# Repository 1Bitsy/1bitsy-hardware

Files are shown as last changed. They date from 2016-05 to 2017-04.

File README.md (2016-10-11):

# 1BitSy



This project includes 1BitSy evaluation boards. These boards are breadboard friendly STM32 (eventually other MCUs will be considered) with exposed Cortex JTAG and SWD interfaces. This allows the use of the Black Magic Probe, instead of the usually very limited built in debugger hardware.

Currently we have the following eval boards:

* 1BitSy V1.0d -> STM32F4x5RGT6

You can find the datasheet of the STM32F415RGT6 chip on the
[STMicroelectronics website](http://www.st.com/content/st_com/en/products/microcontrollers/stm32-32-bit-arm-cortex-mcus/stm32f4-series/stm32f405-415/stm32f415rg.html).

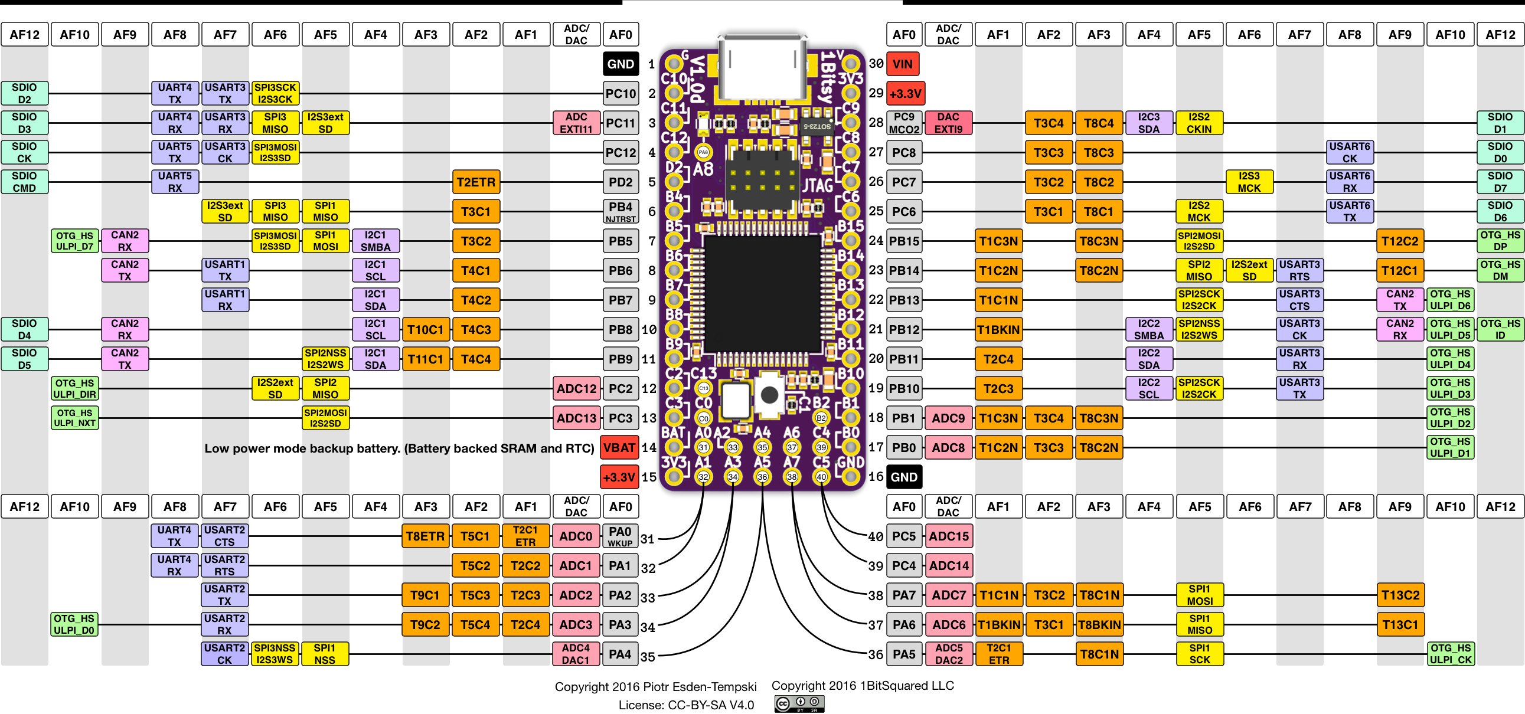
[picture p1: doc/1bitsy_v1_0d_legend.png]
1BitSy V1.0d legend

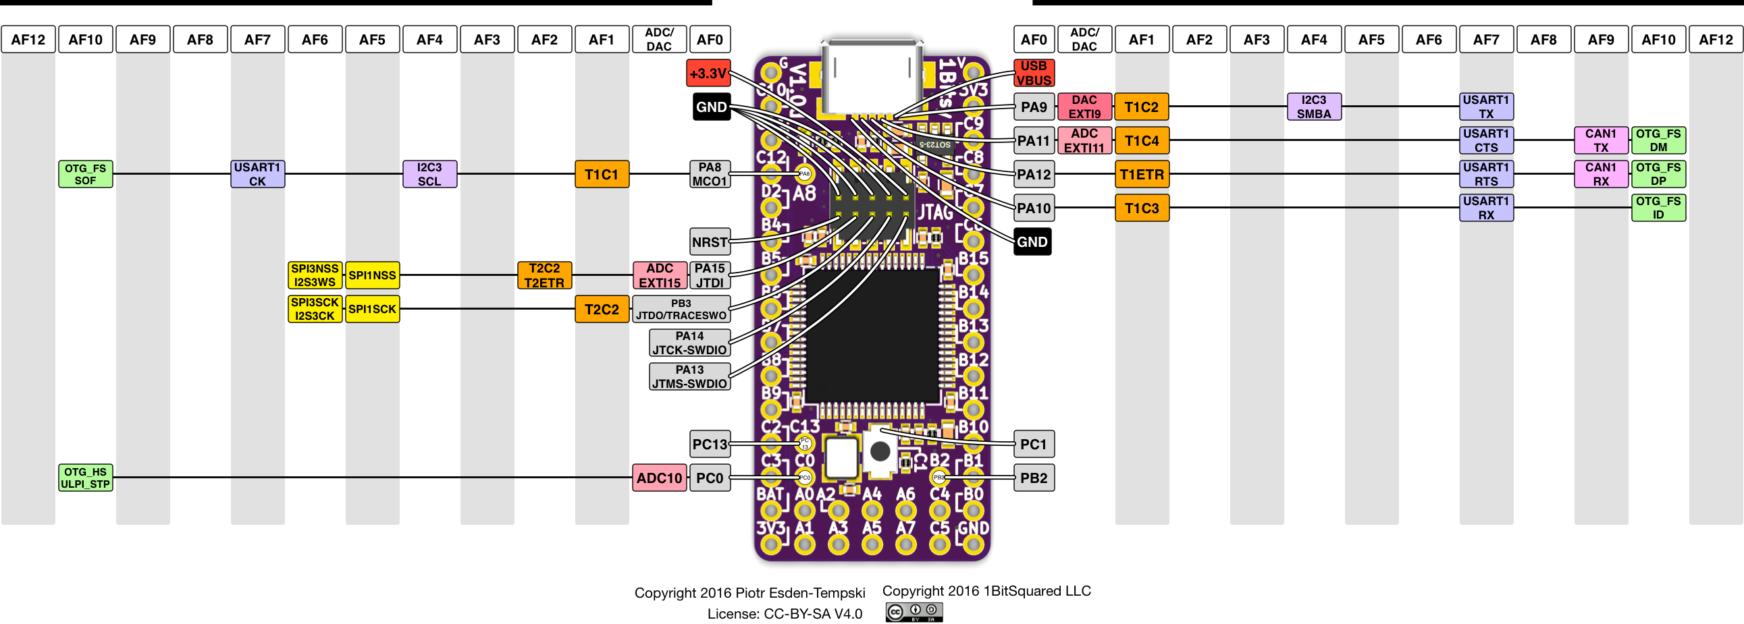
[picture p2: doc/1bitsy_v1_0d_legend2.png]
1BitSy V1.0d legend2

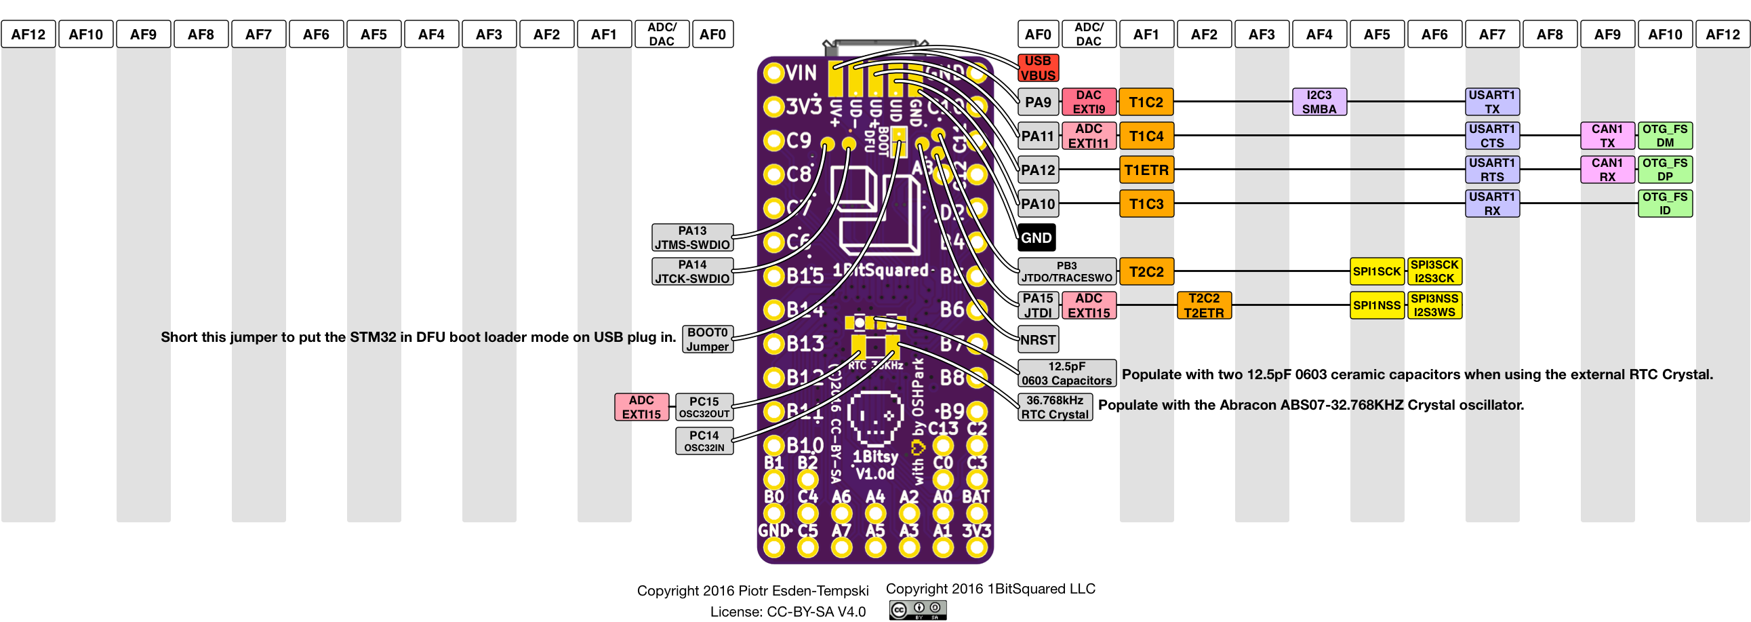
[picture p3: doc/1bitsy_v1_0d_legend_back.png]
1BitSy V1.0d legend back


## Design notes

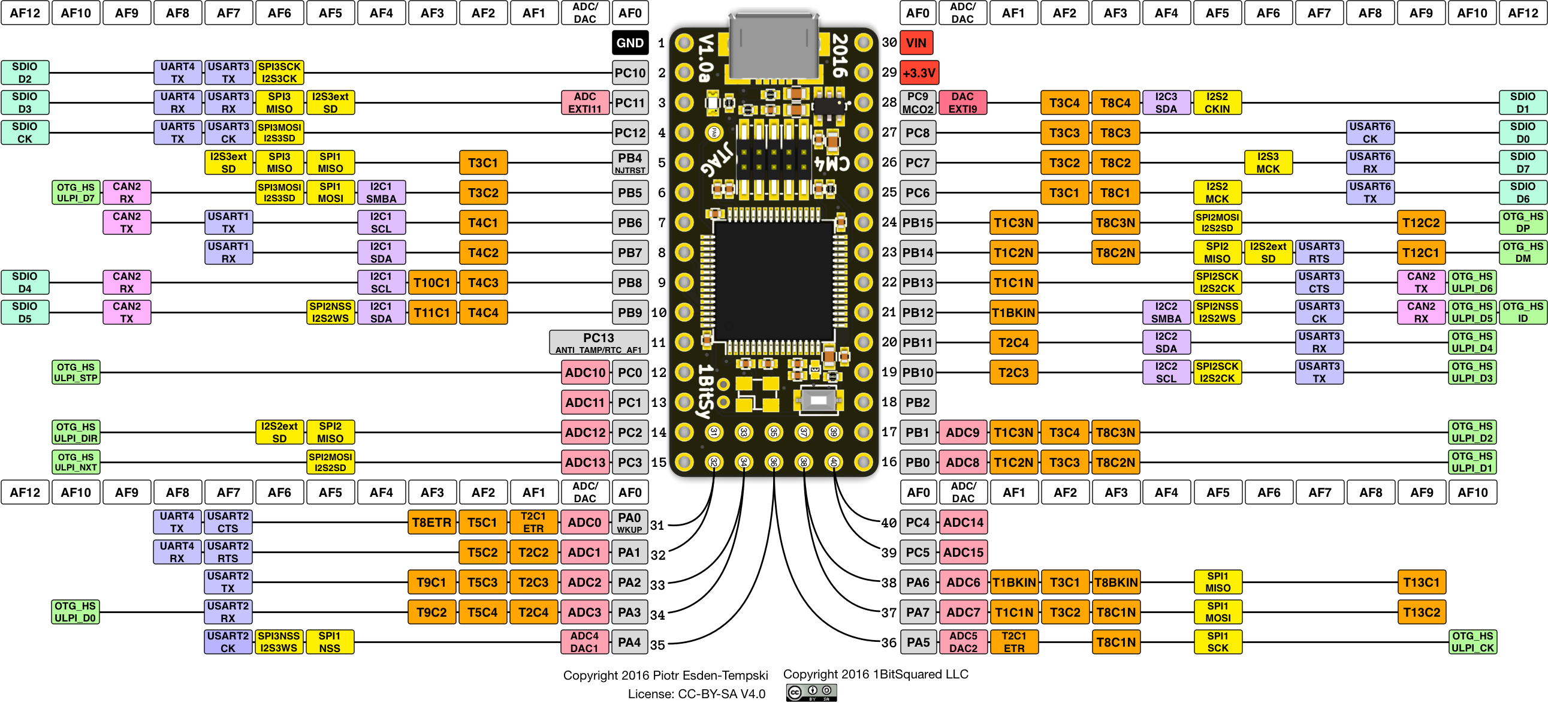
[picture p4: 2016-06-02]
doc/1bitsy_v1_0_legend.png

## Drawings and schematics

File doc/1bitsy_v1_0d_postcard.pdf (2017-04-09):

# 1Bitsy V1.0

# Open-Source debuggable ARM development board

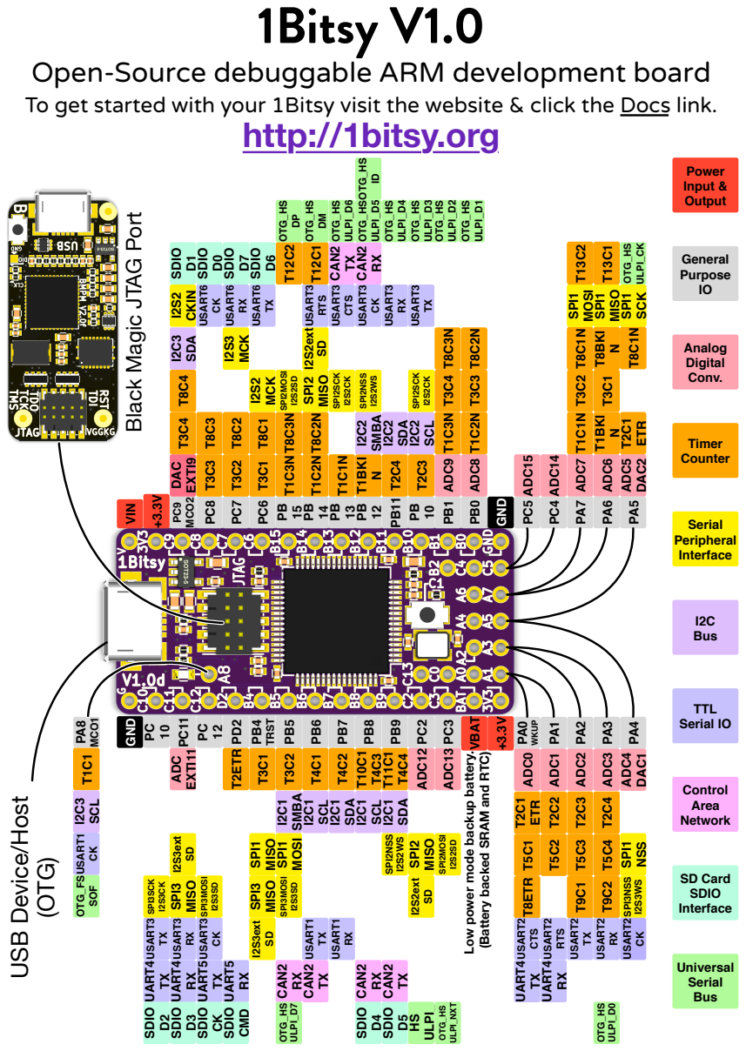
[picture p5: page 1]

To get started with your 1Bitsy visit the website & click the Docs link.

Black Magic JTAG Port

Low power mode backup battery.

(Battery backed SRAM and RTC)

# 1Bitsy V1.0

# Open-Source debuggable ARM development board

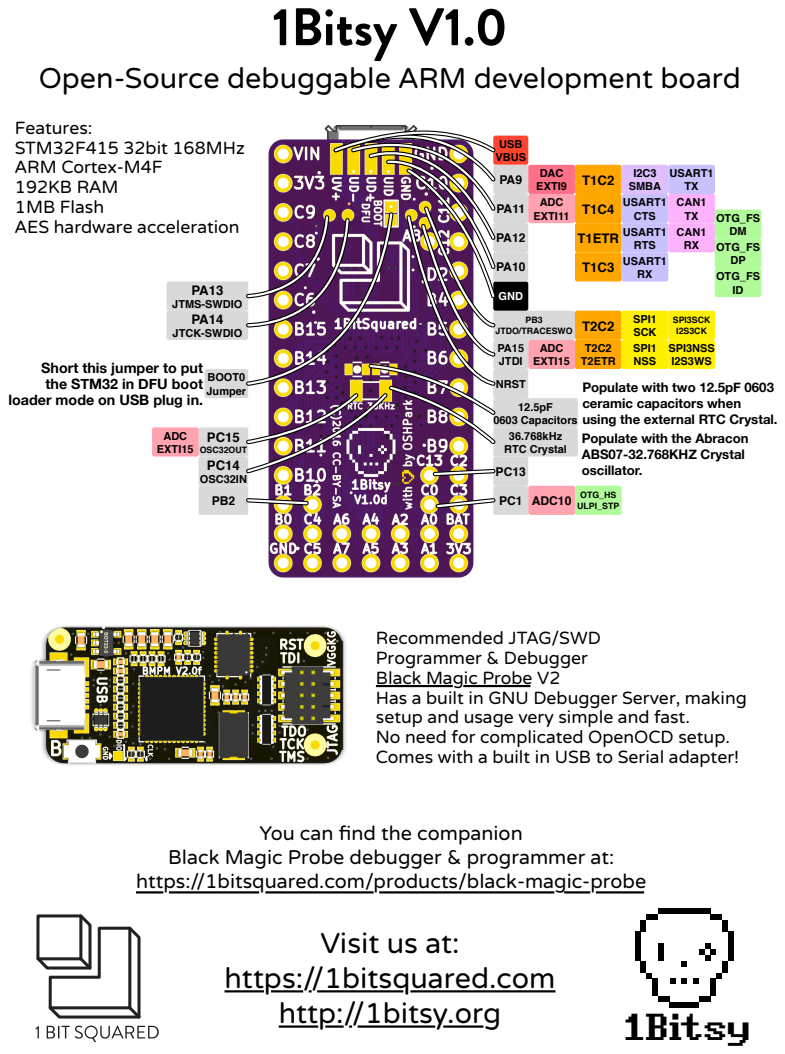
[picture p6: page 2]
USB VBUS; PA13 JTMS-SWDIO; PA14 JTCK-SWDIO; PB3 JTDO/TRACESWO PA15 JTDI; NRST; GND; T1ETR; I2C3 SMBA; USART1 TX; USART1 RX; USART1 CTS USART1 RTS; CAN1 RX; CAN1 TX; OTG_FS ID; OTG_FS DM OTG_FS DP; SPI1 NSS; SPI3NSS I2S3WS; SPI1 SCK; SPI3SCK I2S3CK; BOOT0 Jumper; 36.768kHz RTC Crystal; 12.5pF 0603 Capacitors; OSC32OUT PC14 OSC32IN; ADC EXTI15; ADC EXTI11; DAC EXTI9; ADC10 OTG_HS ULPI_STP; 1Bitsy; Features: STM32F415 32bit 168MHz ARM Cortex-M4F 192KB RAM 1MB Flash AES hardware acceleration

T2ETR
Populate with two 12.5pF 0603
ceramic capacitors when
using the external RTC Crystal.
Populate with the Abracon
ABS07-32.768KHZ Crystal
oscillator.

Short this jumper to put
the STM32 in DFU boot
loader mode on USB plug in.

Recommended JTAG/SWD
Programmer & Debugger
Black Magic Probe V2
Has a built in GNU Debugger Server, making
setup and usage very simple and fast.
No need for complicated OpenOCD setup.
Comes with a built in USB to Serial adapter!

You can find the companion

Black Magic Probe debugger & programmer at:
https://1bitsquared.com/products/black-magic-probe

Visit us at:
https://1bitsquared.com
http://1bitsy.org

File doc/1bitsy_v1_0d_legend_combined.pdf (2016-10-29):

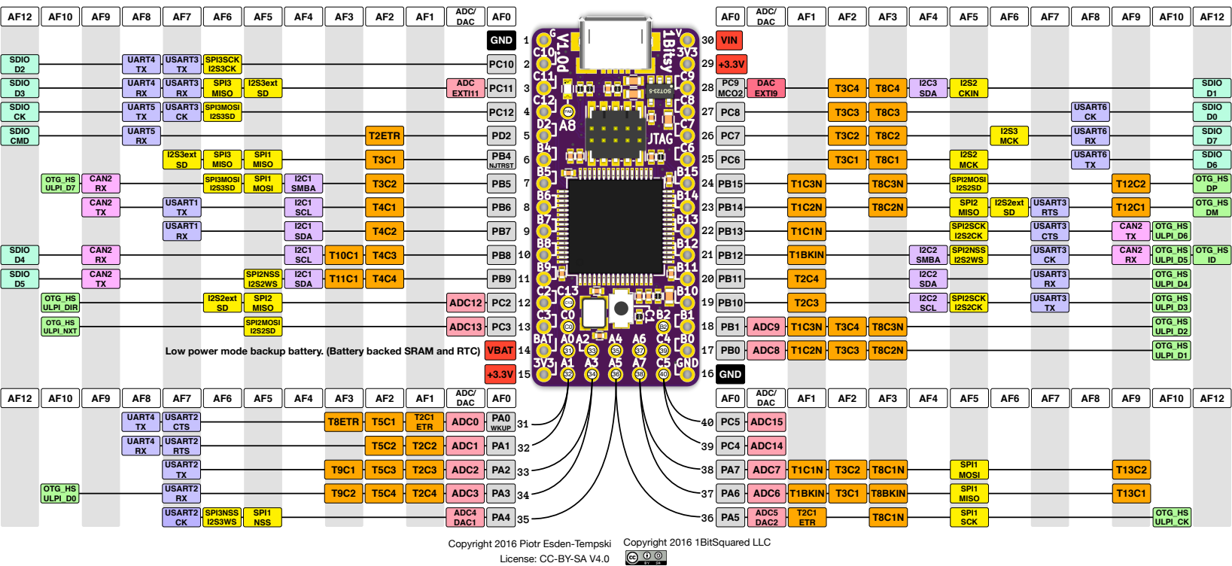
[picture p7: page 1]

Low power mode backup battery. (Battery backed SRAM and RTC) VBAT

ADC4
DAC1
Copyright 2016 Piotr Esden-Tempski Copyright 2016 1BitSquared LLC

License: CC-BY-SA V4.0

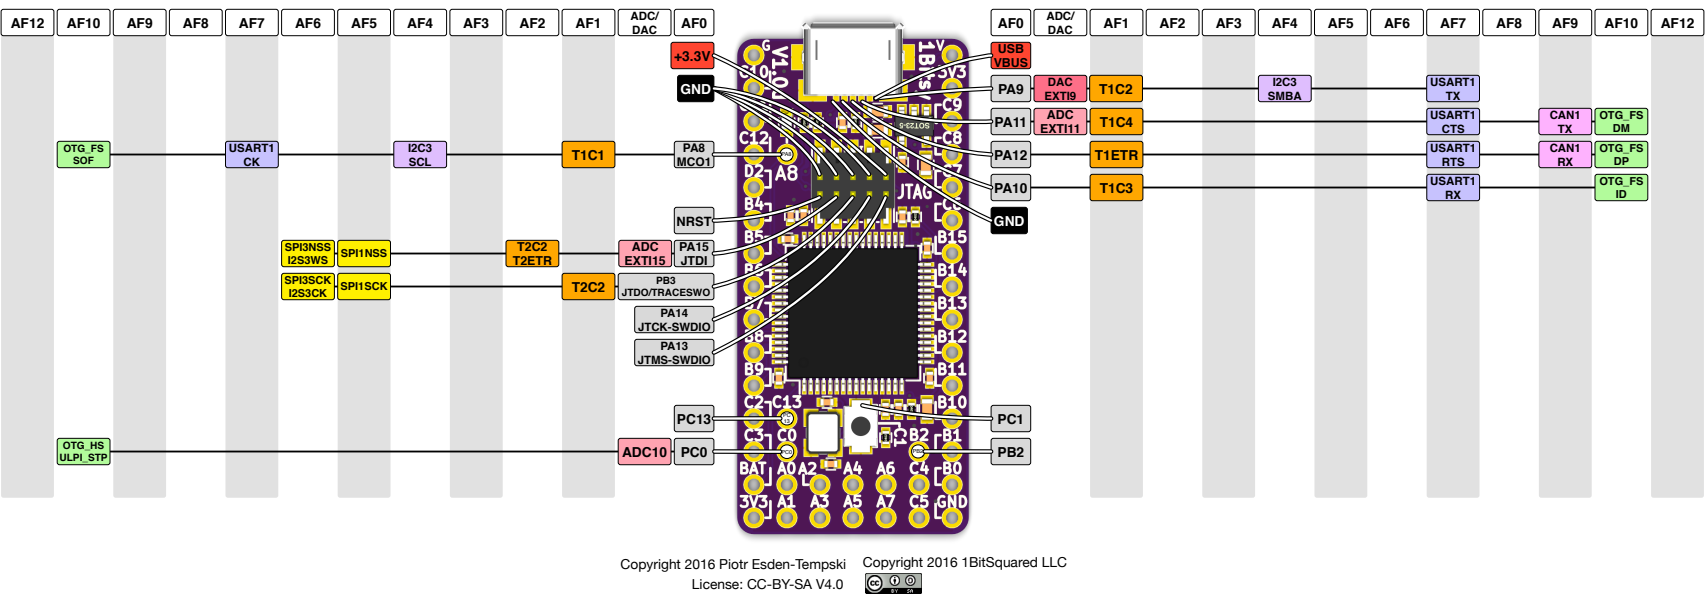
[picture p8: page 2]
ADC10 OTG_HS ULPI_STP; USB VBUS +3.3V; PA13 JTMS-SWDIO; PA14 JTCK-SWDIO; PB3 JTDO/TRACESWO; PA15 JTDI; NRST; PA8 MCO1; DAC AF12; USART1 CK; T2C2 T2ETR; T1C1 I2C3 SCL; OTG_FS SOF; GND; T1ETR; I2C3 SMBA; USART1 TX; USART1 RX; USART1 CTS; USART1 RTS; CAN1 RX; CAN1 TX; OTG_FS ID; OTG_FS DM; OTG_FS DP; SPI1NSS SPI3NSS I2S3WS; SPI1SCK SPI3SCK I2S3CK; ADC EXTI11; DAC EXTI9; ADC EXTI15

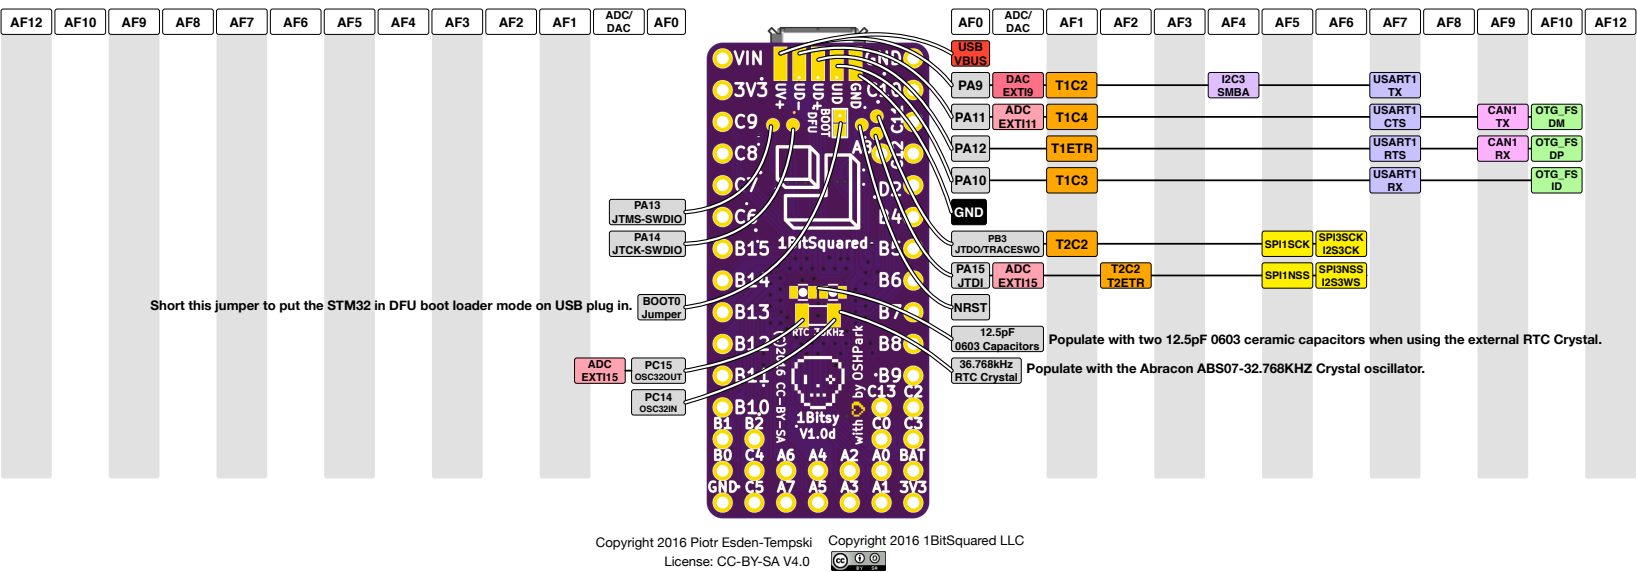
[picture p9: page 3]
USB VBUS; PA13 JTMS-SWDIO; PA14 JTCK-SWDIO; PB3 JTDO/TRACESWO; PA15 JTDI; DAC AF12; T2C2 T2ETR; GND; T1ETR; I2C3 SMBA; USART1 TX; USART1 RX; USART1 CTS; USART1 RTS; CAN1 RX; CAN1 TX; OTG_FS ID; OTG_FS DM; OTG_FS DP; SPI1NSS SPI3NSS I2S3WS; SPI1SCK SPI3SCK I2S3CK; BOOT0; 36.768kHz; PC15 OSC32OUT; PC14 OSC32IN; ADC EXTI15; ADC EXTI11; DAC EXTI9

Jumper Short this jumper to put the STM32 in DFU boot loader mode on USB plug in.

NRST
0603 Capacitors Populate with two 12.5pF 0603 ceramic capacitors when using the external RTC Crystal.
RTC Crystal Populate with the Abracon ABS07-32.768KHZ Crystal oscillator.

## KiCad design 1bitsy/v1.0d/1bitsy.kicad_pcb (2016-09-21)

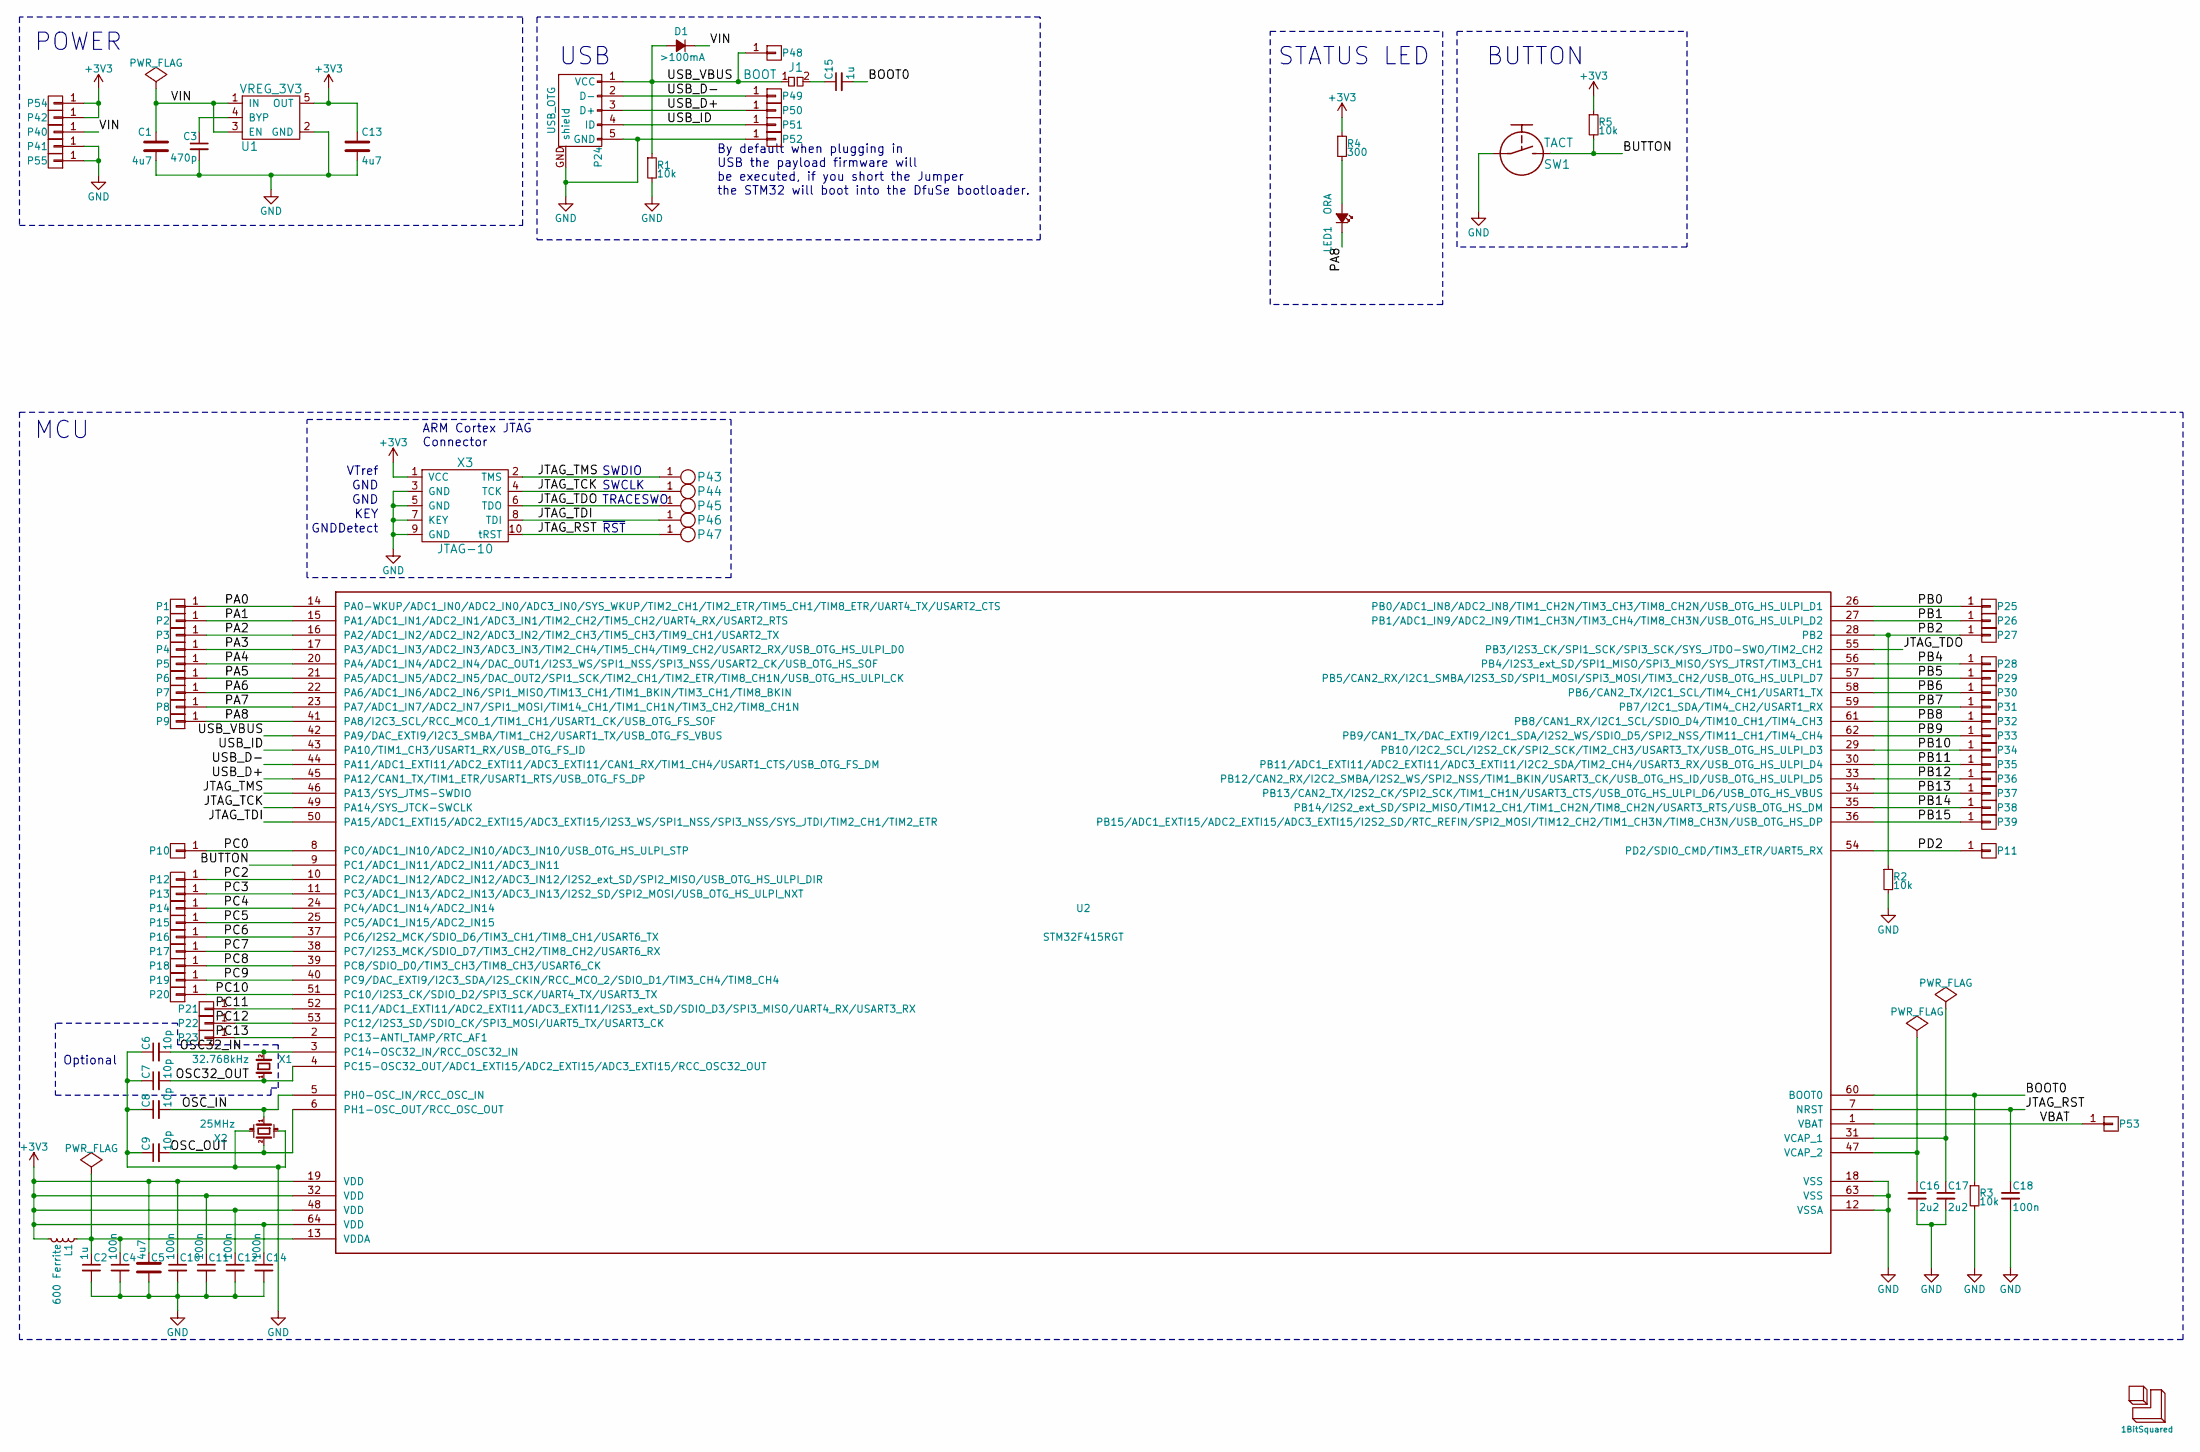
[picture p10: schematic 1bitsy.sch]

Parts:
C1, C5, C13: 4u7; C_0603
C2, C15: 1u; C_0402
C3: 470p; C_0402
C4, C10, C11, C12, C14, C18: 100n; C_0402
C6, C7: 10p; C_0603
C8, C9: 10p; C_0402
C16, C17: 2u2; C_0402
D1: >100mA; D_0603
J1: BOOT; J_0603
L1: 600 Ferrite; L_0402
LED1: ORA; D_0603
LOGO1: 1BitSquared; 1b2_Logo_SilkS_7.5mm
P1, P2, P3, P4, P5, P6, P7, P8, P9, P10, P11, P12, P13, P14, P15, P16, P17, P18, P19, P20, P21, P22, P23, P25, P26, P27, P28, P29, P30, P31, P32, P33, P34, P35, P36, P37, P38, P39, P40, P41, P42, P53, P54, P55: CONN_01X01; Pin_Header_Straight_Round_1x01
P24: USB_OTG; Connector_USB_Micro_B_SMD
P43, P44, P45, P46, P47: TP; POGO_PAD_SMD_R_1x1
P48, P49, P50, P51, P52: CONN_01X01; PAD_SMD_1x2.65
R1, R2, R3, R5: 10k; R_0402
R4: 300; R_0402
SW1: TACT; Tact_Switch_Top_B3U-1000P
U1: VREG_3V3; SOT-23-5
U2: STM32F415RGT; LQFP-64_10x10mm_Pitch0.5mm
X1: 32.768kHz; ABS07
X2: 25MHz; ABM8
X3: JTAG-10; FTSH-105-XX-X-DV

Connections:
+3V3: C5.1, C10.1, C11.1, C12.1, C13.1, C14.1, L1.1, P42.1, P54.1, R4.1, R5.1, U1.5 (OUT), U2.19 (VDD), U2.32 (VDD), U2.48 (VDD), U2.64 (VDD), X3.1 (VCC)
/BOOT0: C15.2, R3.1, U2.60 (BOOT0)
/BUTTON: R5.2, SW1.2, U2.9 (PC1/ADC1_IN11/ADC2_IN11/ADC3_IN11)
/JTAG_RST: C18.1, P47.1, U2.7 (NRST), X3.10 (tRST)
/JTAG_TCK: P44.1, U2.49 (PA14/SYS_JTCK-SWCLK), X3.4 (TCK)
/JTAG_TDI: P46.1, U2.50 (PA15/ADC1_EXTI15/ADC2_EXTI15/ADC3_EXTI1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), X3.8 (TDI)
/JTAG_TDO: P45.1, U2.55 (PB3/I2S3_CK/SPI1_SCK/SPI3_SCK/SYS_JTDO-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), X3.6 (TDO)
/JTAG_TMS: P43.1, U2.46 (PA13/SYS_JTMS-SWDIO), X3.2 (TMS)
/OSC32_IN: C6.2, U2.3 (PC14-OSC32_IN/RCC_OSC32_IN), X1.2
/OSC32_OUT: C7.2, U2.4 (PC15-OSC32_OUT/ADC1_EXTI15/ADC2_EXTI15/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), X1.1
/OSC_IN: C8.2, U2.5 (PH0-OSC_IN/RCC_OSC_IN), X2.1
/OSC_OUT: C9.2, U2.6 (PH1-OSC_OUT/RCC_OSC_OUT), X2.2
/PA0: P1.1, U2.14 (PA0-WKUP/ADC1_IN0/ADC2_IN0/ADC3_IN0/SYS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)
/PA1: P2.1, U2.15 (PA1/ADC1_IN1/ADC2_IN1/ADC3_IN1/TIM2_CH2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)
/PA2: P3.1, U2.16 (PA2/ADC1_IN2/ADC2_IN2/ADC3_IN2/TIM2_CH3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)
/PA3: P4.1, U2.17 (PA3/ADC1_IN3/ADC2_IN3/ADC3_IN3/TIM2_CH4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)
/PA4: P5.1, U2.20 (PA4/ADC1_IN4/ADC2_IN4/DAC_OUT1/I2S3_WS/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)
/PA5: P6.1, U2.21 (PA5/ADC1_IN5/ADC2_IN5/DAC_OUT2/SPI1_SCK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)
/PA6: P7.1, U2.22 (PA6/ADC1_IN6/ADC2_IN6/SPI1_MISO/TIM13_C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)
/PA7: P8.1, U2.23 (PA7/ADC1_IN7/ADC2_IN7/SPI1_MOSI/TIM14_C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)
/PA8: LED1.C, P9.1, U2.41 (PA8/I2C3_SCL/RCC_MCO_1/TIM1_CH1/USART1_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)
/PB0: P25.1, U2.26 (PB0/ADC1_IN8/ADC2_IN8/TIM1_CH2N/TIM3_CH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)
/PB1: P26.1, U2.27 (PB1/ADC1_IN9/ADC2_IN9/TIM1_CH3N/TIM3_CH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)
/PB2: P27.1, R2.1, U2.28 (PB2)
/PB4: P28.1, U2.56 (PB4/I2S3_ext_SD/SPI1_MISO/SPI3_MISO/SYS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)
/PB5: P29.1, U2.57 (PB5/CAN2_RX/I2C1_SMBA/I2S3_SD/SPI1_MOSI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)
/PB6: P30.1, U2.58 (PB6/CAN2_TX/I2C1_SCL/TIM4_CH1/USART1_TX)
/PB7: P31.1, U2.59 (PB7/I2C1_SDA/TIM4_CH2/USART1_RX)
/PB8: P32.1, U2.61 (PB8/CAN1_RX/I2C1_SCL/SDIO_D4/TIM10_CH1/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)
/PB9: P33.1, U2.62 (PB9/CAN1_TX/DAC_EXTI9/I2C1_SDA/I2S2_WS/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)
/PB10: P34.1, U2.29 (PB10/I2C2_SCL/I2S2_CK/SPI2_SCK/TIM2_CH3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)
/PB11: P35.1, U2.30 (PB11/ADC1_EXTI11/ADC2_EXTI11/ADC3_EXTI1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)
/PB12: P36.1, U2.33 (PB12/CAN2_RX/I2C2_SMBA/I2S2_WS/SPI2_NSS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)
/PB13: P37.1, U2.34 (PB13/CAN2_TX/I2S2_CK/SPI2_SCK/TIM1_CH1N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)
/PB14: P38.1, U2.35 (PB14/I2S2_ext_SD/SPI2_MISO/TIM12_CH1/TI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)
/PB15: P39.1, U2.36 (PB15/ADC1_EXTI15/ADC2_EXTI15/ADC3_EXTI1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)
/PC0: P10.1, U2.8 (PC0/ADC1_IN10/ADC2_IN10/ADC3_IN10/USB_O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)
/PC2: P12.1, U2.10 (PC2/ADC1_IN12/ADC2_IN12/ADC3_IN12/I2S2_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)
/PC3: P13.1, U2.11 (PC3/ADC1_IN13/ADC2_IN13/ADC3_IN13/I2S2_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)
/PC4: P14.1, U2.24 (PC4/ADC1_IN14/ADC2_IN14)
/PC5: P15.1, U2.25 (PC5/ADC1_IN15/ADC2_IN15)
/PC6: P16.1, U2.37 (PC6/I2S2_MCK/SDIO_D6/TIM3_CH1/TIM8_CH1/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)
/PC7: P17.1, U2.38 (PC7/I2S3_MCK/SDIO_D7/TIM3_CH2/TIM8_CH2/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)
/PC8: P18.1, U2.39 (PC8/SDIO_D0/TIM3_CH3/TIM8_CH3/USART6_CK)
/PC9: P19.1, U2.40 (PC9/DAC_EXTI9/I2C3_SDA/I2S_CKIN/RCC_MCO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)
/PC10: P20.1, U2.51 (PC10/I2S3_CK/SDIO_D2/SPI3_SCK/UART4_TX/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)
/PC11: P21.1, U2.52 (PC11/ADC1_EXTI11/ADC2_EXTI11/ADC3_EXTI1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)
/PC12: P22.1, U2.53 (PC12/I2S3_SD/SDIO_CK/SPI3_MOSI/UART5_TX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)
/PC13: P23.1, U2.2 (PC13-ANTI_TAMP/RTC_AF1)
/PD2: P11.1, U2.54 (PD2/SDIO_CMD/TIM3_ETR/UART5_RX)
/USB_D+: P24.3 (D+), P50.1, U2.45 (PA12/CAN1_TX/TIM1_ETR/USART1_RTS/USB_OT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)
/USB_D-: P24.2 (D-), P49.1, U2.44 (PA11/ADC1_EXTI11/ADC2_EXTI11/ADC3_EXTI1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)
/USB_ID: P24.4 (ID), P51.1, U2.43 (PA10/TIM1_CH3/USART1_RX/USB_OTG_FS_ID)
/USB_VBUS: D1.A, J1.1, P24.1 (VCC), P48.1, R1.1, U2.42 (PA9/DAC_EXTI9/I2C3_SMBA/TIM1_CH2/USART1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)
/VBAT: P53.1, U2.1 (VBAT)
/VIN: C1.1, D1.C, P40.1, U1.1 (IN), U1.3 (EN)
GND: C1.2, C2.2, C3.2, C4.2, C5.2, C6.1, C7.1, C8.1, C9.1, C10.2, C11.2, C12.2, C13.2, C14.2, C16.2, C17.2, C18.2, P24.5 (GND), P24.GND (shield), P41.1, P52.1, P55.1, R1.2, R2.2, R3.2, SW1.1, U1.2 (GND), U2.12 (VSSA), U2.18 (VSS), U2.63 (VSS), X2.GND (case), X3.3 (GND), X3.5 (GND), X3.7 (KEY), X3.9 (GND)
unnamed: C2.1, C4.1, L1.2, U2.13 (VDDA)
unnamed: C3.1, U1.4 (BYP)
unnamed: C15.1, J1.2
unnamed: C16.1, U2.47 (VCAP_2)
unnamed: C17.1, U2.31 (VCAP_1)
unnamed: LED1.A, R4.2

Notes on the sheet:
SWDIO
SWCLK
TRACESWO
~RST
GND
KEY
GNDDetect
VTref
ARM Cortex JTAG Connector
USB
BUTTON
STATUS LED
MCU
Optional
By default when plugging in USB the payload firmware will be executed, if you short the Jumper the STM32 will boot into the DfuSe bootloader.
POWER

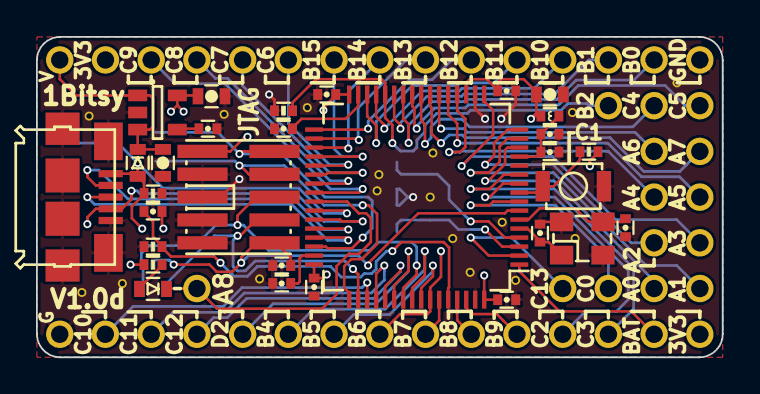
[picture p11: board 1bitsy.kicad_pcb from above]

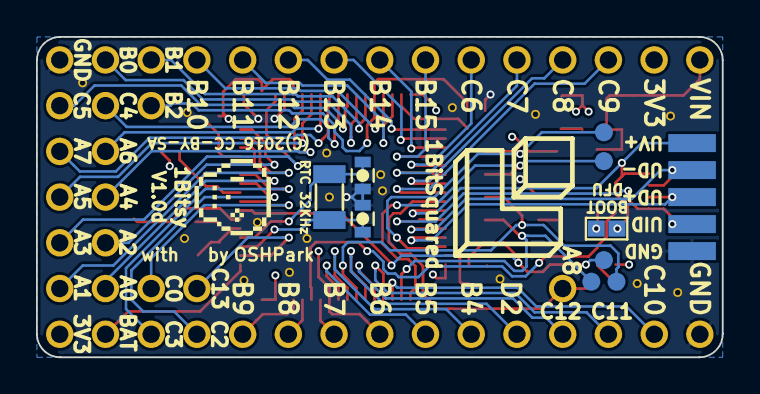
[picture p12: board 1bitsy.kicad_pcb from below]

Board: 4 copper layers, 38.1 x 17.8 mm, 88 parts (14 on the bottom side), 63 nets.

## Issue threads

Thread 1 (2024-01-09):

bootloader not working

babristor, 2024-01-09:
when i press&hold the button while plugging the usb cable noting happen. No dfu mode :
$ dfu-util -l
dfu-util 0.9

Copyright 2005-2009 Weston Schmidt, Harald Welte and OpenMoko Inc.
Copyright 2010-2020 Tormod Volden and Stefan Schmidt
This program is Free Software and has ABSOLUTELY NO WARRANTY
Please report bugs to http://sourceforge.net/p/dfu-util/tickets/

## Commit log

2016-05-25 Initial commit of 1BitSy V1.0a
    [1bitsy.kicad_pcb, 1bitsy.sch]
2016-07-17 Initial commit of V1.0b.
    * Added wire pads for USB
    * Added pogopin pads for JTAG
    [1bitsy.kicad_pcb, 1bitsy.sch]
2016-07-22 First routing pass on 1BitSy V1.0b.
    [1bitsy.kicad_pcb, 1bitsy.sch]
2016-07-22 Some more layout and legend cleanup.
    [1bitsy.kicad_pcb]
2016-07-22 Swapped PA6/PA7 pads to follow pattern. Added pin legend.
    [1bitsy.kicad_pcb]
2016-07-23 Some more silkscreen legend cleanup.
    [1bitsy.kicad_pcb]
2016-07-23 Final prototype production sync.
    [1bitsy.kicad_pcb]
2016-07-23 Forgot to move a GND via.
    [1bitsy.kicad_pcb]
2016-07-23 Fixed a 3v3 via.
    It was not a problem for gerber generation, but the dev kicad branch
    disconnected it on import.
    [1bitsy.kicad_pcb]
2016-07-23 Made the legend split line split.
    [1bitsy.kicad_pcb]
2016-08-15 Improved part ID and Value legend.
    [1bitsy.kicad_pcb]
2016-08-20 Added missing DAC/ADC labels.
2016-08-20 Initial commit of V1.0c.
    Only copy and version bump.
    [1bitsy.kicad_pcb, 1bitsy.sch]
2016-08-21 Exposed the PD2 pin to allow 4pin SDIO.
    The PD2 pin was connected to the button making 4bit SDIO difficult to
    implement. This resulted in a bunch of IO pins changing their positions:
    * Button: PD2 -> PC1
    * 5: PB4 -> PD2
    * 6: PB5 -> PB4
    * 7: PB6 -> PB5
    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
    [1bitsy.kicad_pcb, 1bitsy.sch]
2016-08-22 Changed the boot jumper to 0603 size.
    This should make manual soldering of it slightly easier.
    [1bitsy.kicad_pcb, 1bitsy.sch]
2016-08-22 Updated footprints.
    The new dipol footprints do not have the 0.075mm solderstop opening
    constraint.
    [1bitsy.kicad_pcb]
2016-08-25 Added 1Bitsy logo. Improved back side silkscreen.
    [1bitsy.kicad_pcb]
2016-08-26 A lot of silkscreen work.
    [1bitsy.kicad_pcb]
2016-08-26 More silkscreen polish.
    Made the pixelheart larger, moved some via away from silkscreen lines.
    [1bitsy.kicad_pcb]
2016-08-26 Removed serial pin numbering, left only pin bank+pin no.
    We got rid of the pcb specific numbering to make space for larger
    internal mcu numbering labels. These are much more important when
    writing code for the board.
    [1bitsy.kicad_pcb]
2016-08-27 Some more Silkscreen cleanup work.
    [1bitsy.kicad_pcb]
2016-08-27 Swapped C4 & C5 for consistency.
    [1bitsy.kicad_pcb]
2016-08-27 Updated Fab legend.
    [1bitsy.kicad_pcb]
2016-08-27 Recovered v1.0c pcb revision, added v1.0d.
    [1bitsy.kicad_pcb, 1bitsy.sch]
2016-09-10 Added a rounded rectangle pad 1bitsy v1.0d.
    The rounded rectangles are recommended by IPC. the advantages are:
    * Better flow of pb free solder
    * Better detach of solder paste from stencils
    * Better part joint fillet
    [1bitsy-rr.kicad_pcb]
2016-09-10 Fixed the LS crystal label.
    We had 36KHz but should be 32KHz if anything. (yes we are truncating the
    actual frequency because we lack space for all the stuff behind the
    comma)
    [1bitsy-rr.kicad_pcb, 1bitsy.kicad_pcb]
2016-09-21 Some minor adjustment for pos file generation.
    [1bitsy.kicad_pcb, 1bitsy.sch]
2016-10-11 Added link to the STM32F415RGT6 in the README.
2016-11-14 Added schematic in pdf format.

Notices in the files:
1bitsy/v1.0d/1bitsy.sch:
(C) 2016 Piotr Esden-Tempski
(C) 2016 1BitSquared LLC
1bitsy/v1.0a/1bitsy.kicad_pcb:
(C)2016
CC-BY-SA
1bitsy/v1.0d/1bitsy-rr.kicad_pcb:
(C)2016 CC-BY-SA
